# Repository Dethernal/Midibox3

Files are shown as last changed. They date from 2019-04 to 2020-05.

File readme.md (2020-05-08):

# MidiBox3

My attempt to make new Waveblaster-compatible interface board.

## Features

* Work with all current loop MIDI source
* Additional Note On volume control with rotary encoder
* Can work without microcontroller as simple interface board but other features will gone.

## Plans

Measure power consumption. What maximum current on +5V line is? Do I really need output filter and what parameters it must have? So, I need to characterize all imortant parameters.

Next, there are more components on PCB that really needed for working. Also some components are more expensive than necessary. It will be reasonable to find cheaper ones.

Finally, STM32F103CBT6 is a beast and I love it. It have USB support and I planned use it in next revision of PCB. I don't know about ADC out via USB, but as power source and MIDI in port it will definitely work. Maybe it also may work as HardMPU, but this will require special DOS driver and I think it has lower priority.

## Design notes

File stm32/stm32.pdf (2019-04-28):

## stm32 Project Configuration Report

# 1. Description

## 1.1. Project

Project Name | stm32
Board Name | custom
Generated with: | STM32CubeMX 5.1.0
Date | 04/28/2019

## 1.2. MCU

MCU Series | STM32F1
MCU Line | STM32F103
MCU name | STM32F103CBTx
MCU Package | LQFP48
MCU Pin number | 48

# 2. Pinout Configuration

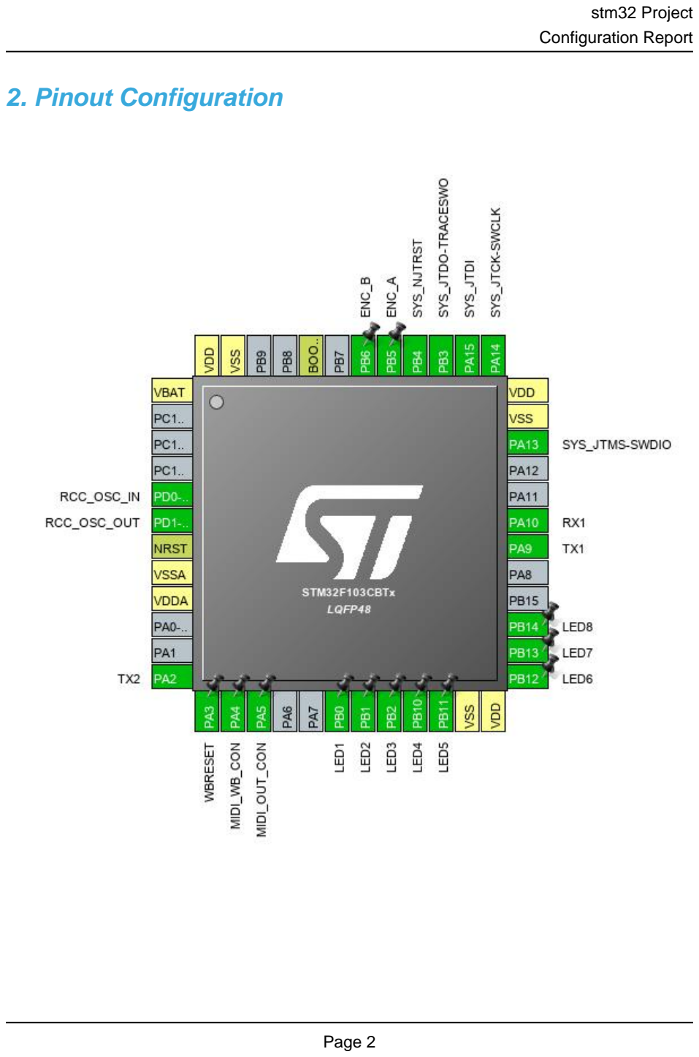
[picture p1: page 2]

# 3. Pins Configuration

Pin Number LQFP48 | Pin Name (function after reset) | Pin Type | Alternate Function(s) | Label
1 | VBAT | Power
5 | PD0-OSC_IN | I/O | RCC_OSC_IN
6 | PD1-OSC_OUT | I/O | RCC_OSC_OUT
7 | NRST | Reset
8 | VSSA | Power
9 | VDDA | Power
12 | PA2 | I/O | USART2_TX | TX2
13 | PA3 * | I/O | GPIO_Output | WBRESET
14 | PA4 * | I/O | GPIO_Output | MIDI_WB_CON
15 | PA5 * | I/O | GPIO_Output | MIDI_OUT_CON
18 | PB0 * | I/O | GPIO_Output | LED1
19 | PB1 * | I/O | GPIO_Output | LED2
20 | PB2 * | I/O | GPIO_Output | LED3
21 | PB10 * | I/O | GPIO_Output | LED4
22 | PB11 * | I/O | GPIO_Output | LED5
23 | VSS | Power
24 | VDD | Power
25 | PB12 * | I/O | GPIO_Output | LED6
26 | PB13 * | I/O | GPIO_Output | LED7
27 | PB14 * | I/O | GPIO_Output | LED8
30 | PA9 | I/O | USART1_TX | TX1
31 | PA10 | I/O | USART1_RX | RX1
34 | PA13 | I/O | SYS_JTMS-SWDIO
35 | VSS | Power
36 | VDD | Power
37 | PA14 | I/O | SYS_JTCK-SWCLK
38 | PA15 | I/O | SYS_JTDI
39 | PB3 | I/O | SYS_JTDO-TRACESWO
40 | PB4 | I/O | SYS_NJTRST
41 | PB5 | I/O | GPIO_EXTI5 | ENC_A
42 | PB6 | I/O | GPIO_EXTI6 | ENC_B
44 | BOOT0 | Boot
47 | VSS | Power
48 | VDD | Power

## * The pin is affected with an I/O function

# 4. Clock Tree Configuration

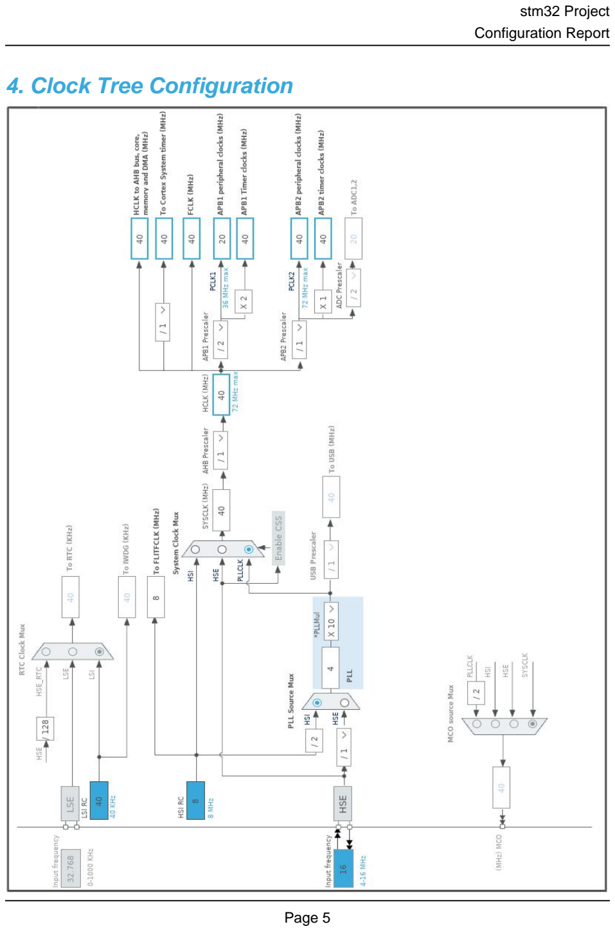
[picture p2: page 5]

# 5. Software Project

## 5.1. Project Settings

Name | Value
Project Name | stm32
Project Folder | /home/nil/KiCADProjects/MidiBox3/stm32
Toolchain / IDE | Makefile
Firmware Package Name and Version | STM32Cube FW_F1 V1.7.0

## 5.2. Code Generation Settings

Name | Value
STM32Cube Firmware Library Package | Copy all used libraries into the project folder
Generate peripheral initialization as a pair of '.c/.h' files | No
Backup previously generated files when re-generating | No
Delete previously generated files when not re-generated | Yes
Set all free pins as analog (to optimize the power consumption) | No

# 6. Power Consumption Calculator report

### 6.1. Microcontroller Selection

Series | STM32F1
Line | STM32F103
MCU | STM32F103CBTx
Datasheet | 13587_Rev17

### 6.2. Parameter Selection

Temperature | 25
Vdd | 3.3

# 7. IPs and Middleware Configuration

# 7.1. RCC

## High Speed Clock (HSE): Crystal/Ceramic Resonator 7.1.1. Parameter Settings:

### System Parameters:

VDD voltage (V) | 3.3
Prefetch Buffer | Enabled
Flash Latency(WS) | 1 WS (2 CPU cycle)

### RCC Parameters:

HSI Calibration Value | 16
HSE Startup Timout Value (ms) | 100
LSE Startup Timout Value (ms) | 5000

# 7.2. SYS

## Debug: JTAG (5 pins) Timebase Source: SysTick

# 7.3. TIM2

## Clock Source : Internal Clock 7.3.1. Parameter Settings:

### Counter Settings:

Prescaler (PSC - 16 bits value) | 0
Counter Mode | Up
Counter Period (AutoReload Register - 16 bits value ) | 10000 *
Internal Clock Division (CKD) | No Division
auto-reload preload | Enable *

### Trigger Output (TRGO) Parameters:

Master/Slave Mode (MSM bit) | Disable (Trigger input effect not delayed)
Trigger Event Selection | Reset (UG bit from TIMx_EGR)

# 7.4. USART1

## Mode: Asynchronous 7.4.1. Parameter Settings:

### Basic Parameters:

Baud Rate | 31250 *
Word Length | 8 Bits (including Parity)
Parity | None
Stop Bits | 1

### Advanced Parameters:

Data Direction | Receive and Transmit
Over Sampling | 16 Samples

# 7.5. USART2

## Mode: Single Wire (Half-Duplex) 7.5.1. Parameter Settings:

### Basic Parameters:

Baud Rate | 115200
Word Length | 8 Bits (including Parity)
Parity | None
Stop Bits | 1

### Advanced Parameters:

Data Direction | Transmit Only *
Over Sampling | 16 Samples

### * User modified value

# 8. System Configuration

# 8.1. GPIO configuration

IP | Pin | Signal | GPIO mode | GPIO pull/up pull down | Max Speed | User Label
RCC | PD0-OSC_IN | RCC_OSC_IN | n/a | n/a | n/a
| PD1-OSC_OUT | RCC_OSC_OUT | n/a | n/a | n/a
SYS | PA13 | SYS_JTMS-SWDIO | n/a | n/a | n/a
| PA14 | SYS_JTCK-SWCLK | n/a | n/a | n/a
| PA15 | SYS_JTDI | n/a | n/a | n/a
| PB3 | SYS_JTDO-TRACESWO | n/a | n/a | n/a
| PB4 | SYS_NJTRST | n/a | n/a | n/a
USART1 | PA9 | USART1_TX | Alternate Function Push Pull | n/a | High * | TX1
| PA10 | USART1_RX | Input mode | No pull-up and no pull-down | n/a | RX1
USART2 | PA2 | USART2_TX | Alternate Function Open Drain | n/a | High * | TX2
GPIO | PA3 | GPIO_Output | Output Push Pull | No pull-up and no pull-down | Low | WBRESET
PA4 | GPIO_Output | Output Open Drain * | No pull-up and no pull-down | Low | MIDI_WB_CON
PA5 | GPIO_Output | Output Open Drain * | No pull-up and no pull-down | Low | MIDI_OUT_CON
PB0 | GPIO_Output | Output Push Pull | Pull-down * | Low | LED1
PB1 | GPIO_Output | Output Push Pull | Pull-down * | Low | LED2
PB2 | GPIO_Output | Output Push Pull | Pull-down * | Low | LED3
PB10 | GPIO_Output | Output Push Pull | Pull-down * | Low | LED4
PB11 | GPIO_Output | Output Push Pull | Pull-down * | Low | LED5
PB12 | GPIO_Output | Output Push Pull | Pull-down * | Low | LED6
PB13 | GPIO_Output | Output Push Pull | Pull-down * | Low | LED7
PB14 | GPIO_Output | Output Push Pull | Pull-down * | Low | LED8
PB5 | GPIO_EXTI5 | External Interrupt Mode with Rising/Falling edge | No pull-up and no pull-down | n/a | ENC_A
PB6 | GPIO_EXTI6 | External Interrupt Mode with Falling edge trigger detection | No pull-up and no pull-down | n/a | ENC_B

# 8.2. DMA configuration

## nothing configured in DMA service

# 8.3. NVIC configuration

Interrupt Table | Enable | Preenmption Priority | SubPriority
Non maskable interrupt | true | 0 | 0
Hard fault interrupt | true | 0 | 0
Memory management fault | true | 0 | 0
Prefetch fault, memory access fault | true | 0 | 0
Undefined instruction or illegal state | true | 0 | 0
System service call via SWI instruction | true | 0 | 0
Debug monitor | true | 0 | 0
Pendable request for system service | true | 0 | 0
System tick timer | true | 0 | 0
TIM2 global interrupt | true | 0 | 0
USART1 global interrupt | true | 0 | 0
PVD interrupt through EXTI line 16 | unused
Flash global interrupt | unused
RCC global interrupt | unused
EXTI line[9:5] interrupts | unused
USART2 global interrupt | unused

### * User modified value

# 9. Software Pack Report

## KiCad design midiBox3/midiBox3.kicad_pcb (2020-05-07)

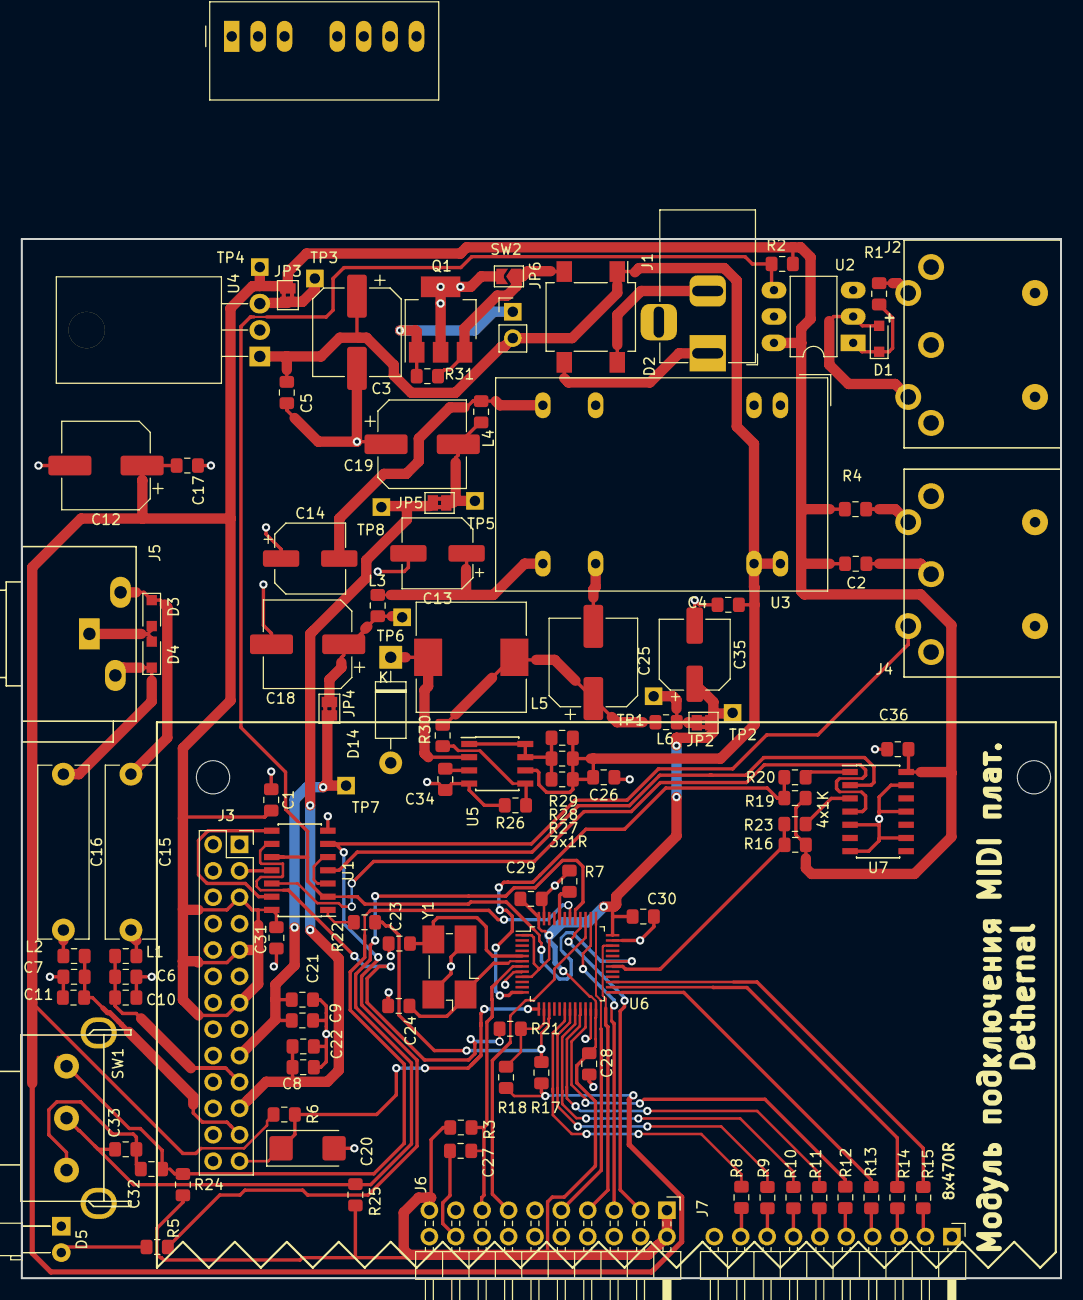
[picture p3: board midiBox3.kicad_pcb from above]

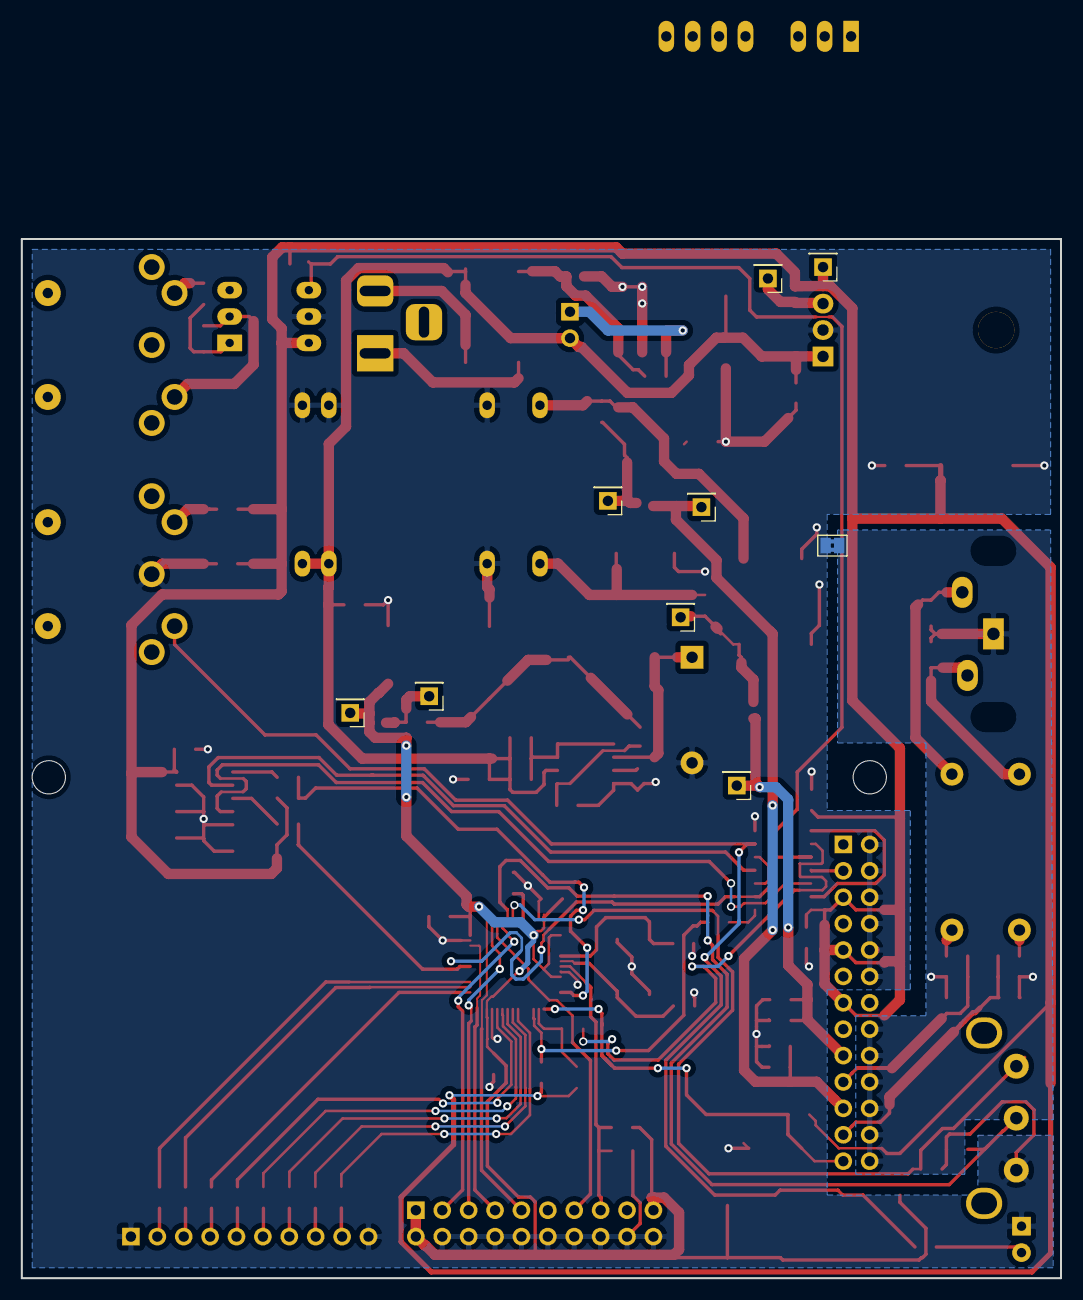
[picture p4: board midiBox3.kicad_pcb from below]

Board: 2 copper layers, 100.0 x 100.0 mm, 111 parts (9 on the bottom side), 76 nets.

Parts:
C1, C2, C8, C9, C27, C28, C31, C36: 100pF; C_0805_2012Metric_Pad1.15x1.40mm_HandSolder
C3, C12, C18, C19, C25: 220uF; CP_Elec_8x6.9
C4, C5, C17, C21, C22, C26: 1uF; C_0805_2012Metric_Pad1.15x1.40mm_HandSolder
C6, C7: 47pF; C_0805_2012Metric_Pad1.15x1.40mm_HandSolder
C10, C11, C23, C24: 15pF; C_0805_2012Metric_Pad1.15x1.40mm_HandSolder
C13, C14, C35: 47uF; CP_Elec_6.3x5.9
C15, C16: 1uF; C_Rect_L16.5mm_W4.7mm_P15.00mm_MKT
C20: 10uF; CP_EIA-6032-15_Kemet-U_Pad2.25x2.35mm_HandSolder
C29, C32, C33: 100nF; C_0805_2012Metric_Pad1.15x1.40mm_HandSolder
C30: 10nF; C_0805_2012Metric_Pad1.15x1.40mm_HandSolder
C34: 470pF; C_0805_2012Metric_Pad1.15x1.40mm_HandSolder
D1: 1N4148; D_SOD-323_HandSoldering
D2: DB104; Diode_Bridge_Vishay_DFSFlat
D3, D4: PESD5V0S1BA; D_SOD-323_HandSoldering
D5: LED; LED_D3.0mm_Horizontal_O3.81mm_Z2.0mm
D14: 1N5819; D_DO-41_SOD81_P10.16mm_Horizontal
J1: BarrelJack; BarrelJack_Horizontal
J2: DIN5 IN; DS-5-01
J3: WaveBlaster; PinSocket_2x13_P2.54mm_Vertical
J4: DIN5 OUT; DS-5-01
J5: RSA 2x; RCA_Dual_Jack_Board_RS-209_03x3mm_Vertical
J6: STM32_PROG; PinHeader_2x10_P2.54mm_Horizontal
J7: LED_CON; PinHeader_1x10_P2.54mm_Horizontal
JP1, JP2, JP3, JP4, JP5: SolderJumper-2_P1.3mm_Bridged2Bar_Pad1.0x1.5mm
JP6: shunt; SolderJumper-2_P1.3mm_Open_TrianglePad1.0x1.5mm
L1, L2: 100nH; L_0805_2012Metric_Pad1.15x1.40mm_HandSolder
L3, L4: 33nH; L_0805_2012Metric_Pad1.15x1.40mm_HandSolder
L5: 220 uH; L_10.4x10.4_H4.8
L6: 100 nH; L_0805_2012Metric_Pad1.15x1.40mm_HandSolder
Q1: IRFL110; SOT-223
R1: 510R; R_0805_2012Metric_Pad1.15x1.40mm_HandSolder
R2: 270R; R_0805_2012Metric_Pad1.15x1.40mm_HandSolder
R3, R6, R24, R25: 10K; R_0805_2012Metric_Pad1.15x1.40mm_HandSolder
R4: 220R; R_0805_2012Metric_Pad1.15x1.40mm_HandSolder
R5, R8, R9, R10, R11, R12, R13, R14, R15: 470R; R_0805_2012Metric_Pad1.15x1.40mm_HandSolder
R7: 4.7K; R_0805_2012Metric_Pad1.15x1.40mm_HandSolder
R16, R17, R18, R19, R20, R21, R22, R23: 1K; R_0805_2012Metric_Pad1.15x1.40mm_HandSolder
R26: 1.5K; R_0805_2012Metric_Pad1.15x1.40mm_HandSolder
R27, R28, R29: 1R; R_0805_2012Metric_Pad1.15x1.40mm_HandSolder
R30: 2.7K; R_0805_2012Metric_Pad1.15x1.40mm_HandSolder
R31: 22K; R_0805_2012Metric_Pad1.15x1.40mm_HandSolder
SW1: D_VALUE; Rotary_Encoder_Bourns_PEC16-2215F-N0024_Horizontal_16mm
SW2: SW_Reed; PinHeader_1x02_P2.54mm_Vertical
TP1, TP2, TP3, TP4, TP5, TP6, TP7, TP8: PinHeader_1x01_P2.54mm_Vertical
U1: 74HCT00; SOIC-14_3.9x8.7mm_P1.27mm
U2: H11L1; DIP-6_W7.62mm_LongPads
U3: JTE0624D12; Converter_DCDC_XP_POWER_JTExxxxDxx_THT
U4: L7805; TO-220-3_Horizontal_TabDown
U5: MC33063AD; SOIC-8_3.9x4.9mm_P1.27mm
U6: STM32F103CBT6; LQFP-48_7x7mm_P0.5mm
U7: 74ACT04; SOIC-14_3.9x8.7mm_P1.27mm
Y1: 16MHz; Crystal_SMD_0603-4Pin_6.0x3.5mm_HandSoldering

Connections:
+3V3: C28.2, C29.2, C30.2, C35.1, J6.1, J6.2, J6.19, JP2.2, R3.2, R24.2, R25.2, TP2.1, U6.1, U6.9, U6.24, U6.36, U6.48
+5V: C1.2, C2.2, C12.1, C17.1, C31.2, C36.2, J3.5, J3.9, J3.13, JP3.2, R2.2, R4.2, R6.1, R16.2, R17.2, R18.2, R19.2, TP4.1, U1.14, U2.6, U7.14
+12V: C9.1, C21.1, J3.17, JP4.2, TP7.1
-12V: C8.1, C22.2, J3.21, JP5.2, TP8.1
/+12NF: C13.1, L3.1, U3.14
/+IN12V: C3.1, C4.1, C5.1, C26.1, D2.1, R27.2, R28.2, R29.2, SW2.2, U3.22, U3.23, U4.1, U5.6
/-12NF: C14.2, L4.1, U3.11
/ENC_A: C33.2, R25.1, SW1.B, U6.41
/ENC_B: C32.1, R24.1, SW1.A, U6.42
/JNTRST: J6.3, U6.40
/JTCK_SWCLK: J6.9, U6.37
/JTDI: J6.5, U6.38
/JTDO-TRACESWO: J6.13, U6.39
/JTMS-SWDIO: J6.7, U6.34
/LEFT: C7.1, C11.1, J3.23, L2.1
/MIDI_IN: R2.1, U1.2, U1.10, U2.4, U6.31
/MIDI_N: D1.2, J2.4, U2.2
/MIDI_OUT_CON: R22.2, U1.1
/MIDI_P: D1.1, R1.1, U2.1
/MIDI_WB: J3.3, U1.11
/MIDI_WB_CON: R21.2, U1.9
/NRST: C27.2, J6.15, R3.1, U6.7
/RIGHT: C6.1, C10.1, J3.19, L1.1
/TX1: R23.2, U7.3
/TX2: R20.2, U7.1
/~RESET: C20.1, J3.25, R6.2, U6.13
GNDA: C6.2, C7.2, C10.2, C11.2, D3.2, D4.2, J3.16, J3.18, J3.20, J3.22, J3.24, J3.26, J5.3, JP1.2
GNDD: C1.1, C2.1, C3.2, C4.2, C5.2, C8.2, C9.2, C12.2, C13.2, C14.1, C17.2, C18.2, C19.1, C20.2, C21.2, C22.1, C23.2, C24.2, C25.2, C26.2, C27.1, C28.1, C29.1, C30.1, C31.1, C32.2, C33.1, C34.2, C35.2, C36.1, D5.1, D14.2, J3.2, J3.4, J3.6, J3.8, J3.10, J3.12, J4.2, J6.4, J6.6, J6.8, J6.10, J6.12, J6.14, J6.16, J6.18, J6.20, J7.1, J7.10, JP1.1, JP6.2, Q1.2, Q1.4, R7.2, R26.1, SW1.C, U1.7, U2.5, U3.2, U3.3, U3.9, U3.16, U4.2, U5.4, U6.8, U6.23, U6.35, U6.47, U7.5, U7.7, U7.9, U7.11, U7.13, Y1.2, Y1.4
unnamed: C15.1, D3.1, J5.1
unnamed: C15.2, L1.2
unnamed: C16.1, D4.1, J5.2
unnamed: C16.2, L2.2
unnamed: C18.1, JP4.1, L3.2, TP6.1
unnamed: C19.2, JP5.1, L4.2, TP5.1
unnamed: C23.1, U6.5, Y1.3
unnamed: C24.1, U6.6, Y1.1
unnamed: C25.1, L5.2, L6.1, R30.2
unnamed: C34.1, U5.3
unnamed: D2.2, JP6.1, Q1.3, R31.1
unnamed: D2.3, J1.1
unnamed: D2.4, J1.2
unnamed: D5.2, R5.1
unnamed: D14.1, L5.1, U5.2
unnamed: J2.5, R1.2
unnamed: J4.4, R5.2, U1.6
unnamed: J4.5, R4.1
unnamed: J7.2, R15.2
unnamed: J7.3, R14.2
unnamed: J7.4, R13.2
unnamed: J7.5, R12.2
unnamed: J7.6, R11.2
unnamed: J7.7, R10.2
unnamed: J7.8, R9.2
unnamed: J7.9, R8.2
unnamed: JP2.1, L6.2, TP1.1
unnamed: JP3.1, TP3.1, U4.3
unnamed: Q1.1, R31.2, SW2.1
unnamed: R7.1, U6.44
unnamed: R8.1, U6.18
unnamed: R9.1, U6.19
unnamed: R10.1, U6.20
unnamed: R11.1, U6.21
unnamed: R12.1, U6.22
unnamed: R13.1, U6.25
unnamed: R14.1, U6.26
unnamed: R15.1, U6.27
unnamed: R16.1, R23.1, U6.30
unnamed: R17.1, R22.1, U6.15
unnamed: R18.1, R21.1, U6.14
unnamed: R19.1, R20.1, U6.12
unnamed: R26.2, R30.1, U5.5
unnamed: R27.1, R28.1, R29.1, U5.1, U5.7, U5.8
unnamed: U1.3, U1.5
unnamed: U1.4, U7.2
unnamed: U1.12, U7.4
unnamed: U1.8, U1.13

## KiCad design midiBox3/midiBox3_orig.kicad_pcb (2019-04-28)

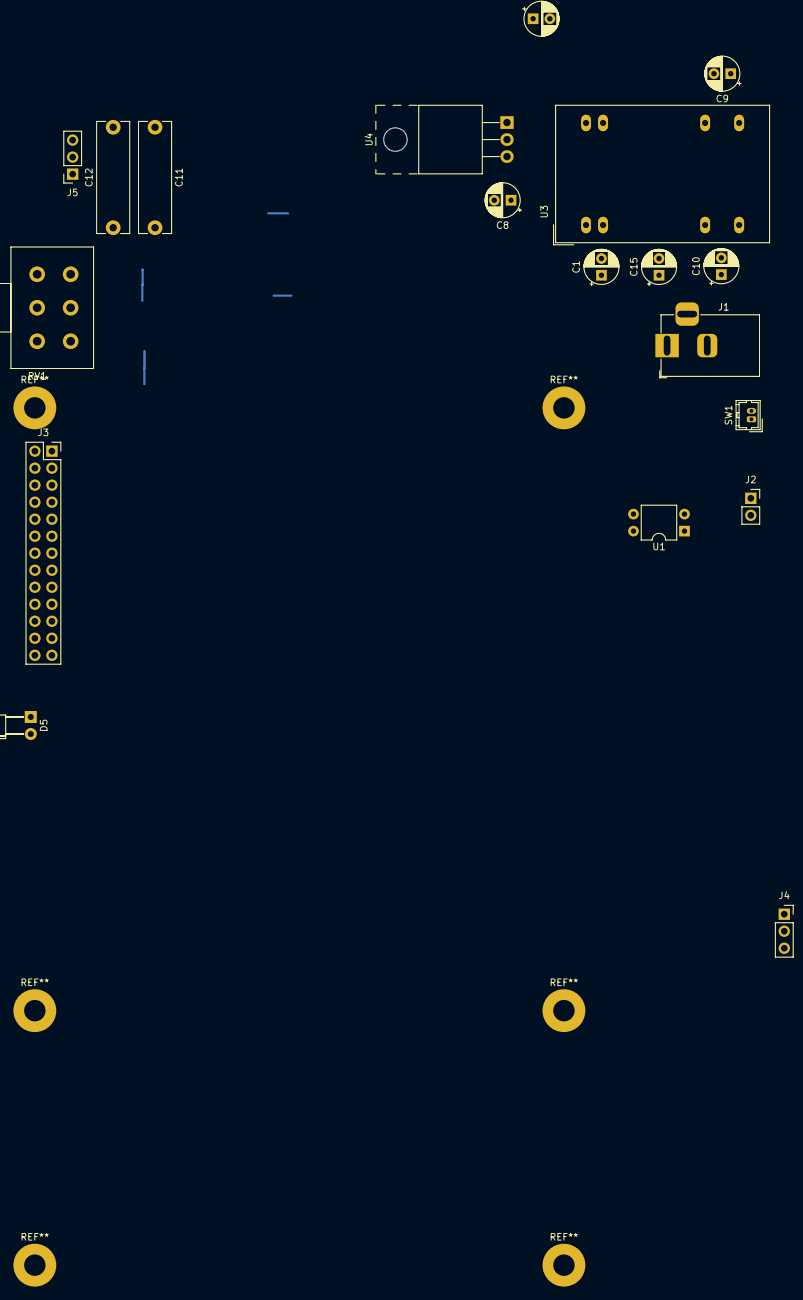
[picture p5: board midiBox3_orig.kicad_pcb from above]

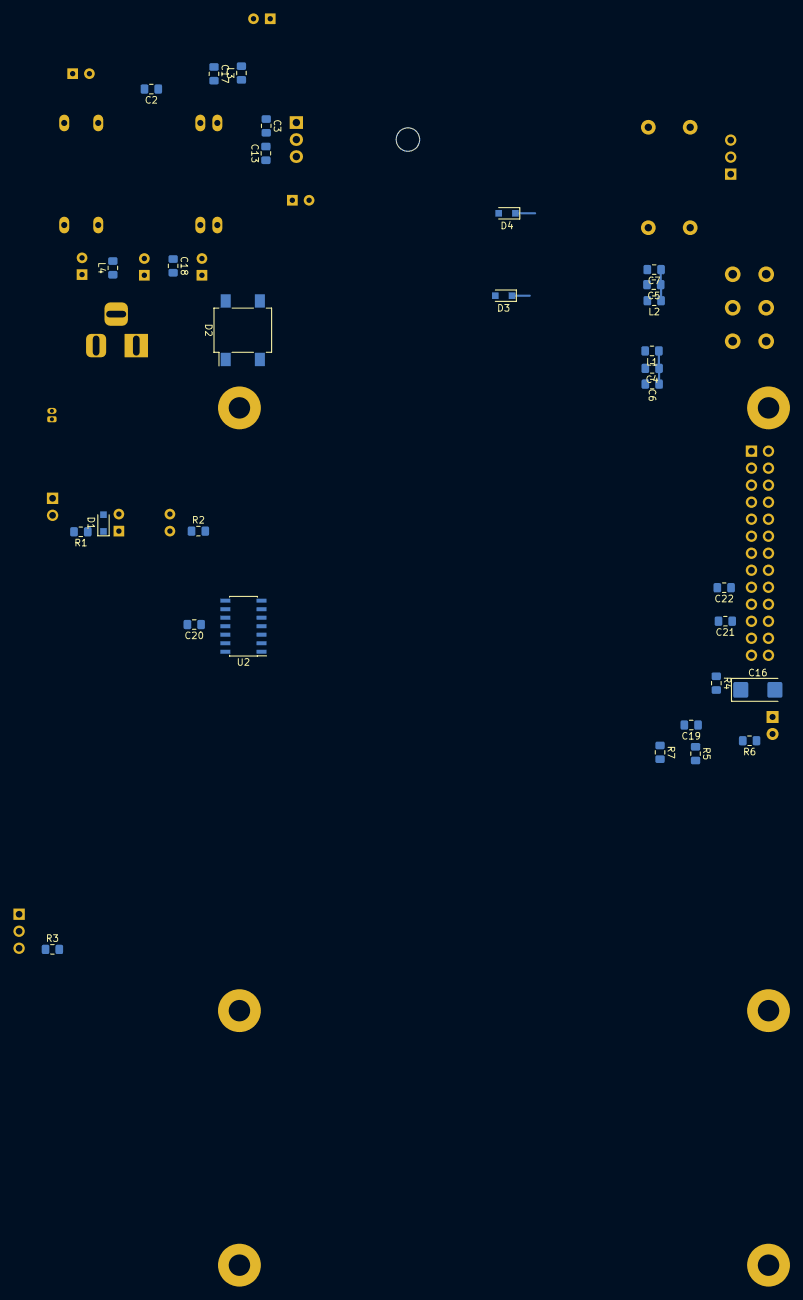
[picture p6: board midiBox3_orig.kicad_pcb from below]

Board: 2 copper layers, 49 parts (30 on the bottom side), 29 nets.

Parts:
C1, C8, C14, C15: 220uF; CP_Radial_D5.0mm_P2.50mm
C2, C3, C13, C17, C18: 1uF; C_0805_2012Metric_Pad1.15x1.40mm_HandSolder
C4, C5: 47pF; C_0805_2012Metric_Pad1.15x1.40mm_HandSolder
C6, C7: 15pF; C_0805_2012Metric_Pad1.15x1.40mm_HandSolder
C9, C10: 47uF; CP_Radial_D5.0mm_P2.50mm
C11, C12: 1uF; C_Rect_L16.5mm_W4.7mm_P15.00mm_MKT
C16: 10uF; CP_EIA-6032-15_Kemet-U_Pad2.25x2.35mm_HandSolder
C19, C20, C21, C22: 100pF; C_0805_2012Metric_Pad1.15x1.40mm_HandSolder
D1: 1N4148; D_SOD-323_HandSoldering
D2: DB104; Diode_Bridge_Vishay_DFSFlat
D3, D4: PESD5V0S1BA; D_SOD-323_HandSoldering
D5: LED; LED_D3.0mm_Horizontal_O3.81mm_Z2.0mm
J1: Barrel_Jack_Switch; BarrelJack_Horizontal
J2: H2; PinSocket_1x02_P2.54mm_Vertical
J3: Conn_02x13_Odd_Even; PinSocket_2x13_P2.54mm_Vertical
J4: H3; PinSocket_1x03_P2.54mm_Vertical
J5: Conn_Coaxial_x2; PinSocket_1x03_P2.54mm_Vertical
L1, L2: 100nH; L_0805_2012Metric_Pad1.15x1.40mm_HandSolder
L3, L4: 33nH; L_0805_2012Metric_Pad1.15x1.40mm_HandSolder
R1, R3: 220R; R_0805_2012Metric_Pad1.15x1.40mm_HandSolder
R2: 4.7K; R_0805_2012Metric_Pad1.15x1.40mm_HandSolder
R4: 10K; R_0805_2012Metric_Pad1.15x1.40mm_HandSolder
R5, R7: 0R; R_0805_2012Metric_Pad1.15x1.40mm_HandSolder
R6: 470R; R_0805_2012Metric_Pad1.15x1.40mm_HandSolder
RV1: R_POT_Dual; Potentiometer_Alps_RK163_Dual_Horizontal
SW1: SW_DIP_x01; Hirose_DF13-02P-1.25DSA_1x02_P1.25mm_Vertical
U1: PC817; DIP-4_W7.62mm
U2: MM74HCT00M; SOIC-14_3.9x8.7mm_P1.27mm
U3: JTE0624D12; Converter_DCDC_XP_POWER_JTExxxxDxx_THT
U4: LM7805_TO220; TO-220-3_Horizontal_TabUp

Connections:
+5V: C8.1, C13.1, C19.1, C20.1, J3.3, J3.5, J3.9, J3.13, R2.2, R3.2, R4.1, U2.11, U2.14, U4.3
+12V: C14.1, C17.1, C22.1, J3.17, L3.2
-12V: C15.1, C18.2, C21.1, J3.21, L4.2
/LEFT: J3.23, RV1.2
/RIGHT: J3.19, RV1.5
/~RESET: C16.1, J3.25, R4.2
GND: C1.2, C2.2, C3.2, C4.2, C5.2, C6.2, C7.2, C8.2, C9.2, C10.2, C13.2, C14.2, C15.2, C16.2, C17.2, C18.1, C19.2, C20.2, C21.2, C22.2, D2.4, D3.2, D4.2, D5.1, J3.2, J3.4, J3.6, J3.8, J3.10, J3.12, J3.16, J3.18, J3.20, J3.22, J3.24, J3.26, J4.2, J5.3, RV1.1, RV1.4, U1.3, U2.7, U3.2, U3.3, U3.9, U3.16, U4.2
unnamed: C1.1, C2.1, C3.1, D2.3, U3.22, U3.23, U4.1
unnamed: C4.1, C6.1, L1.1, RV1.6
unnamed: C5.1, C7.1, L2.1, RV1.3
unnamed: C9.1, L3.1, U3.14
unnamed: C10.1, L4.1, U3.11
unnamed: C11.1, D3.1, J5.1
unnamed: C11.2, L1.2
unnamed: C12.1, D4.1, J5.2
unnamed: C12.2, L2.2
unnamed: D1.1, R1.1, U1.1
unnamed: D1.2, J2.2, U1.2
unnamed: D2.1, SW1.2
unnamed: D2.2, J1.1
unnamed: D5.2, R6.1
unnamed: J1.2, SW1.1
unnamed: J2.1, R1.2
unnamed: J4.1, R7.2, U2.6
unnamed: J4.3, R3.1
unnamed: R2.1, U1.4, U2.1, U2.2, U2.9, U2.10
unnamed: R5.1, R6.2, R7.1
unnamed: R5.2, U2.3, U2.4, U2.5
unnamed: U2.8, U2.12, U2.13

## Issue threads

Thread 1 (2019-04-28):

J2 DIN5 MIDI IN was flipped

Dethernal, 2019-04-28:
Fixed in scematic file but not in pcb. Pin 4 and pin 5 need to be flipped.

Dethernal, 2019-04-30:
Fixed in f5dd57f92eab12fdf74cafd2312ce0510c35c8c5

Closed 2019-04-30.

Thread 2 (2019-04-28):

U2 optodecoupler out not compatible with U1 4x2NAND TTL in

Dethernal, 2019-04-28:
R2 need to be adjusted (but looks like resistance may wary so it need to be adjustable), or U2 need to be replaced with another chip (h11l1 for example).

Dethernal, 2019-05-02:
Fixed in 406650214dfa49212fc3fb581478cd8ac97b7ebb

Closed 2019-05-02.

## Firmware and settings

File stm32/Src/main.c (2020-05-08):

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

/* Includes ------------------------------------------------------------------*/
#include "main.h"

/* USER CODE BEGIN Includes */
#include "export.h"
#include "utils.h"
#include "iobuffers.h"
#include "midi_in_handler.h"
/* USER CODE END Includes */


/* USER CODE BEGIN PV */

uint32_t prev_encoder_pos;

/* USER CODE END PV */

void SystemClock_Config(void);
static void MX_GPIO_Init(void);
static void MX_USART1_UART_Init(void);
static void MX_USART2_UART_Init(void);
static void MX_TIM2_Init(void);
static void MX_TIM4_Init(void);
static void MX_NVIC_Init(void);
/**
  * @brief  The application entry point.
  * @retval int
  */
int main(void)
{
  /* MCU Configuration--------------------------------------------------------*/

  /* Reset of all peripherals, Initializes the Flash interface and the Systick. */
  

  LL_APB2_GRP1_EnableClock(LL_APB2_GRP1_PERIPH_AFIO);
  LL_APB1_GRP1_EnableClock(LL_APB1_GRP1_PERIPH_PWR);

  NVIC_SetPriorityGrouping(NVIC_PRIORITYGROUP_4);

  /* System interrupt init*/

  /** ENABLE: Full SWJ (JTAG-DP + SW-DP): Reset State 
  */
  LL_GPIO_AF_EnableRemap_SWJ();

  /* Configure the system clock */
  SystemClock_Config();

  /* Initialize all configured peripherals */
  MX_GPIO_Init();
  MX_USART1_UART_Init();
  MX_USART2_UART_Init();
  MX_TIM2_Init();
  MX_TIM4_Init();

  /* Initialize interrupts */
  MX_NVIC_Init();
  /* USER CODE BEGIN 2 */

    //LL_GPIO_ResetOutputPin(MIDI_WB_CON_GPIO_Port, MIDI_WB_CON_Pin);




    current_intercept_mode = VOLUME_VELOCITY;
    current_alteration_mode = VOLUME_MULTIPLY;
    current_max_volume = 255;

  /* USER CODE END 2 */

  /* Infinite loop */
  /* USER CODE BEGIN WHILE */

    prev_encoder_pos =
            (LL_GPIO_IsInputPinSet(ENC_B_GPIO_Port, ENC_B_Pin) ? 1 : 0) +
            (LL_GPIO_IsInputPinSet(ENC_A_GPIO_Port, ENC_A_Pin) ? 2 : 0);

    LL_GPIO_ResetOutputPin(MIDI_OUT_CON_GPIO_Port, MIDI_OUT_CON_Pin);
    LL_GPIO_ResetOutputPin(MIDI_WB_CON_GPIO_Port, MIDI_WB_CON_Pin);

    LL_GPIO_ResetOutputPin(WBRESET_GPIO_Port, WBRESET_Pin);
    LL_mDelay(1000);
    LL_GPIO_SetOutputPin(WBRESET_GPIO_Port, WBRESET_Pin);


    NVIC_DisableIRQ(USART1_IRQn);
    NVIC_DisableIRQ(USART2_IRQn);
    MPU401_Init();

    LL_USART_ClearFlag_TC(USART1);
    LL_USART_ClearFlag_TC(USART2);

    LL_USART_DisableIT_TXE(USART1);
    LL_USART_DisableIT_TXE(USART2);

    NVIC_ClearPendingIRQ(USART1_IRQn);
    NVIC_ClearPendingIRQ(USART2_IRQn);

    NVIC_EnableIRQ(USART1_IRQn);
    NVIC_EnableIRQ(USART2_IRQn);

    LL_USART_EnableIT_RXNE(USART1);

    LL_USART_EnableIT_TC(USART1);
    LL_USART_EnableIT_TC(USART2);

    LL_TIM_ClearFlag_UPDATE(TIM2);
    LL_TIM_ClearFlag_UPDATE(TIM4);

    LL_TIM_EnableIT_UPDATE(TIM2);
    LL_TIM_EnableIT_UPDATE(TIM4);

    LL_TIM_ClearFlag_TRIG(TIM2);
    LL_TIM_EnableCounter(TIM2);

    while(1);

    /* USER CODE END WHILE */

}

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


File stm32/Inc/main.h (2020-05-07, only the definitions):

#define TX2_Pin LL_GPIO_PIN_2
#define TX2_GPIO_Port GPIOA
#define WBRESET_Pin LL_GPIO_PIN_3
#define WBRESET_GPIO_Port GPIOA
#define MIDI_WB_CON_Pin LL_GPIO_PIN_4
#define MIDI_WB_CON_GPIO_Port GPIOA
#define MIDI_OUT_CON_Pin LL_GPIO_PIN_5
#define MIDI_OUT_CON_GPIO_Port GPIOA
#define LED1_Pin LL_GPIO_PIN_0
#define LED1_GPIO_Port GPIOB
#define LED2_Pin LL_GPIO_PIN_1
#define LED2_GPIO_Port GPIOB
#define LED3_Pin LL_GPIO_PIN_2
#define LED3_GPIO_Port GPIOB
#define LED4_Pin LL_GPIO_PIN_10
#define LED4_GPIO_Port GPIOB
#define LED5_Pin LL_GPIO_PIN_11
#define LED5_GPIO_Port GPIOB
#define LED6_Pin LL_GPIO_PIN_12
#define LED6_GPIO_Port GPIOB
#define LED7_Pin LL_GPIO_PIN_13
#define LED7_GPIO_Port GPIOB
#define LED8_Pin LL_GPIO_PIN_14
#define LED8_GPIO_Port GPIOB
#define TX1_Pin LL_GPIO_PIN_9
#define TX1_GPIO_Port GPIOA
#define RX1_Pin LL_GPIO_PIN_10
#define RX1_GPIO_Port GPIOA
#define ENC_A_Pin LL_GPIO_PIN_5
#define ENC_A_GPIO_Port GPIOB
#define ENC_A_EXTI_IRQn EXTI9_5_IRQn
#define ENC_B_Pin LL_GPIO_PIN_6
#define ENC_B_GPIO_Port GPIOB
#define ENC_B_EXTI_IRQn EXTI9_5_IRQn
#define NVIC_PRIORITYGROUP_0         ((uint32_t)0x00000007) /*!< 0 bit  for pre-emption priority,
#define NVIC_PRIORITYGROUP_1         ((uint32_t)0x00000006) /*!< 1 bit  for pre-emption priority,
#define NVIC_PRIORITYGROUP_2         ((uint32_t)0x00000005) /*!< 2 bits for pre-emption priority,
#define NVIC_PRIORITYGROUP_3         ((uint32_t)0x00000004) /*!< 3 bits for pre-emption priority,
#define NVIC_PRIORITYGROUP_4         ((uint32_t)0x00000003) /*!< 4 bits for pre-emption priority,
#define INTERNAL_USART USART1
#define EXTERNAL_USART USART2

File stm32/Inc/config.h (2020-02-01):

/*  Copyright (C) 2015		 ab0tj
 *
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
 *  You should have received a copy of the GNU General Public License
 *  along with this program; if not, write to the Free Software
 *  Foundation, Inc., 59 Temple Place - Suite 330, Boston, MA 02111-1307, USA.
 */

 /* config.h: AVR specific configuration details */

#ifndef __CONFIG
#define __CONFIG

#include "main.h"

// pins
#define PIN_IDW		(1<<PORTB3)	// isa output latch CLK
#define PIN_IDR		(1<<PORTB4)	// isa input latch OC
#define PIN_DSR		(1<<PORTB0)	// isa data out flip-flop
#define PIN_DRR		(1<<PORTB1)	// isa data in flip-flop
#define PIN_CRR		(1<<PORTB2)	// isa command in flip-flop;
#define PIN_LED		(1<<PORTC6)	// test LED
#define PIN_TEST	(1<<PORTC7)	// test mode indicator

// parameters
#define F_CPU		20000000UL
#define BAUD_MIDI	39			// 31250
#define BAUD_UART	10			// 115200-ish

#endif

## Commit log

2019-04-30 Changed pcb, fix issue 1
    [midiBox3.kicad_pcb]
2019-05-01 Added new chip — 7404.
    Because TX signals need to be inverted and MST32 lack of abilities to do so. Updated chematic and pcb.
    [midiBox3.kicad_pcb, midiBox3.sch]
2019-05-02 Replaced U2 PC817 with H11L1
    [midiBox3.kicad_pcb, midiBox3.sch]
2020-02-01 Промежуточная версия. Нужно рассчиать какие дополнительные таймеры потребуются для работы.
    [midiBox3.kicad_pcb, midiBox3.sch]
2020-05-04 Начало реальной работы над HardMPU
2020-05-07 Fiddling here and there.
    [midiBox3.kicad_pcb]
2020-05-12 New PCB
    [midiBox3_b.kicad_pcb]

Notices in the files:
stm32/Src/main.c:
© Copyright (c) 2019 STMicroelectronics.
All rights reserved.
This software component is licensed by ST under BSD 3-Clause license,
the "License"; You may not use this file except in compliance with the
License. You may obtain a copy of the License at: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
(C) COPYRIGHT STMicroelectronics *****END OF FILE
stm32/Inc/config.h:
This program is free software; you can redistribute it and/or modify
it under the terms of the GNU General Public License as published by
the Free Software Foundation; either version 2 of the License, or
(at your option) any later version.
